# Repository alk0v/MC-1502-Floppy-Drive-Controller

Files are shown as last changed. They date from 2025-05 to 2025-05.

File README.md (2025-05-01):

# Floppy Drive Controller for Electronika MC-1502 computer
Replica of Floppy Drive Controller for Electronica MC-1502 Computer
Based on the original PCB, Zorel and Val_DP remakes.
The original design was developed in Jun 1991 by Kurapin (design), Tokar (checked), Safat (tested), and Teslenko (approved).

MC1502_FDC_Gerber

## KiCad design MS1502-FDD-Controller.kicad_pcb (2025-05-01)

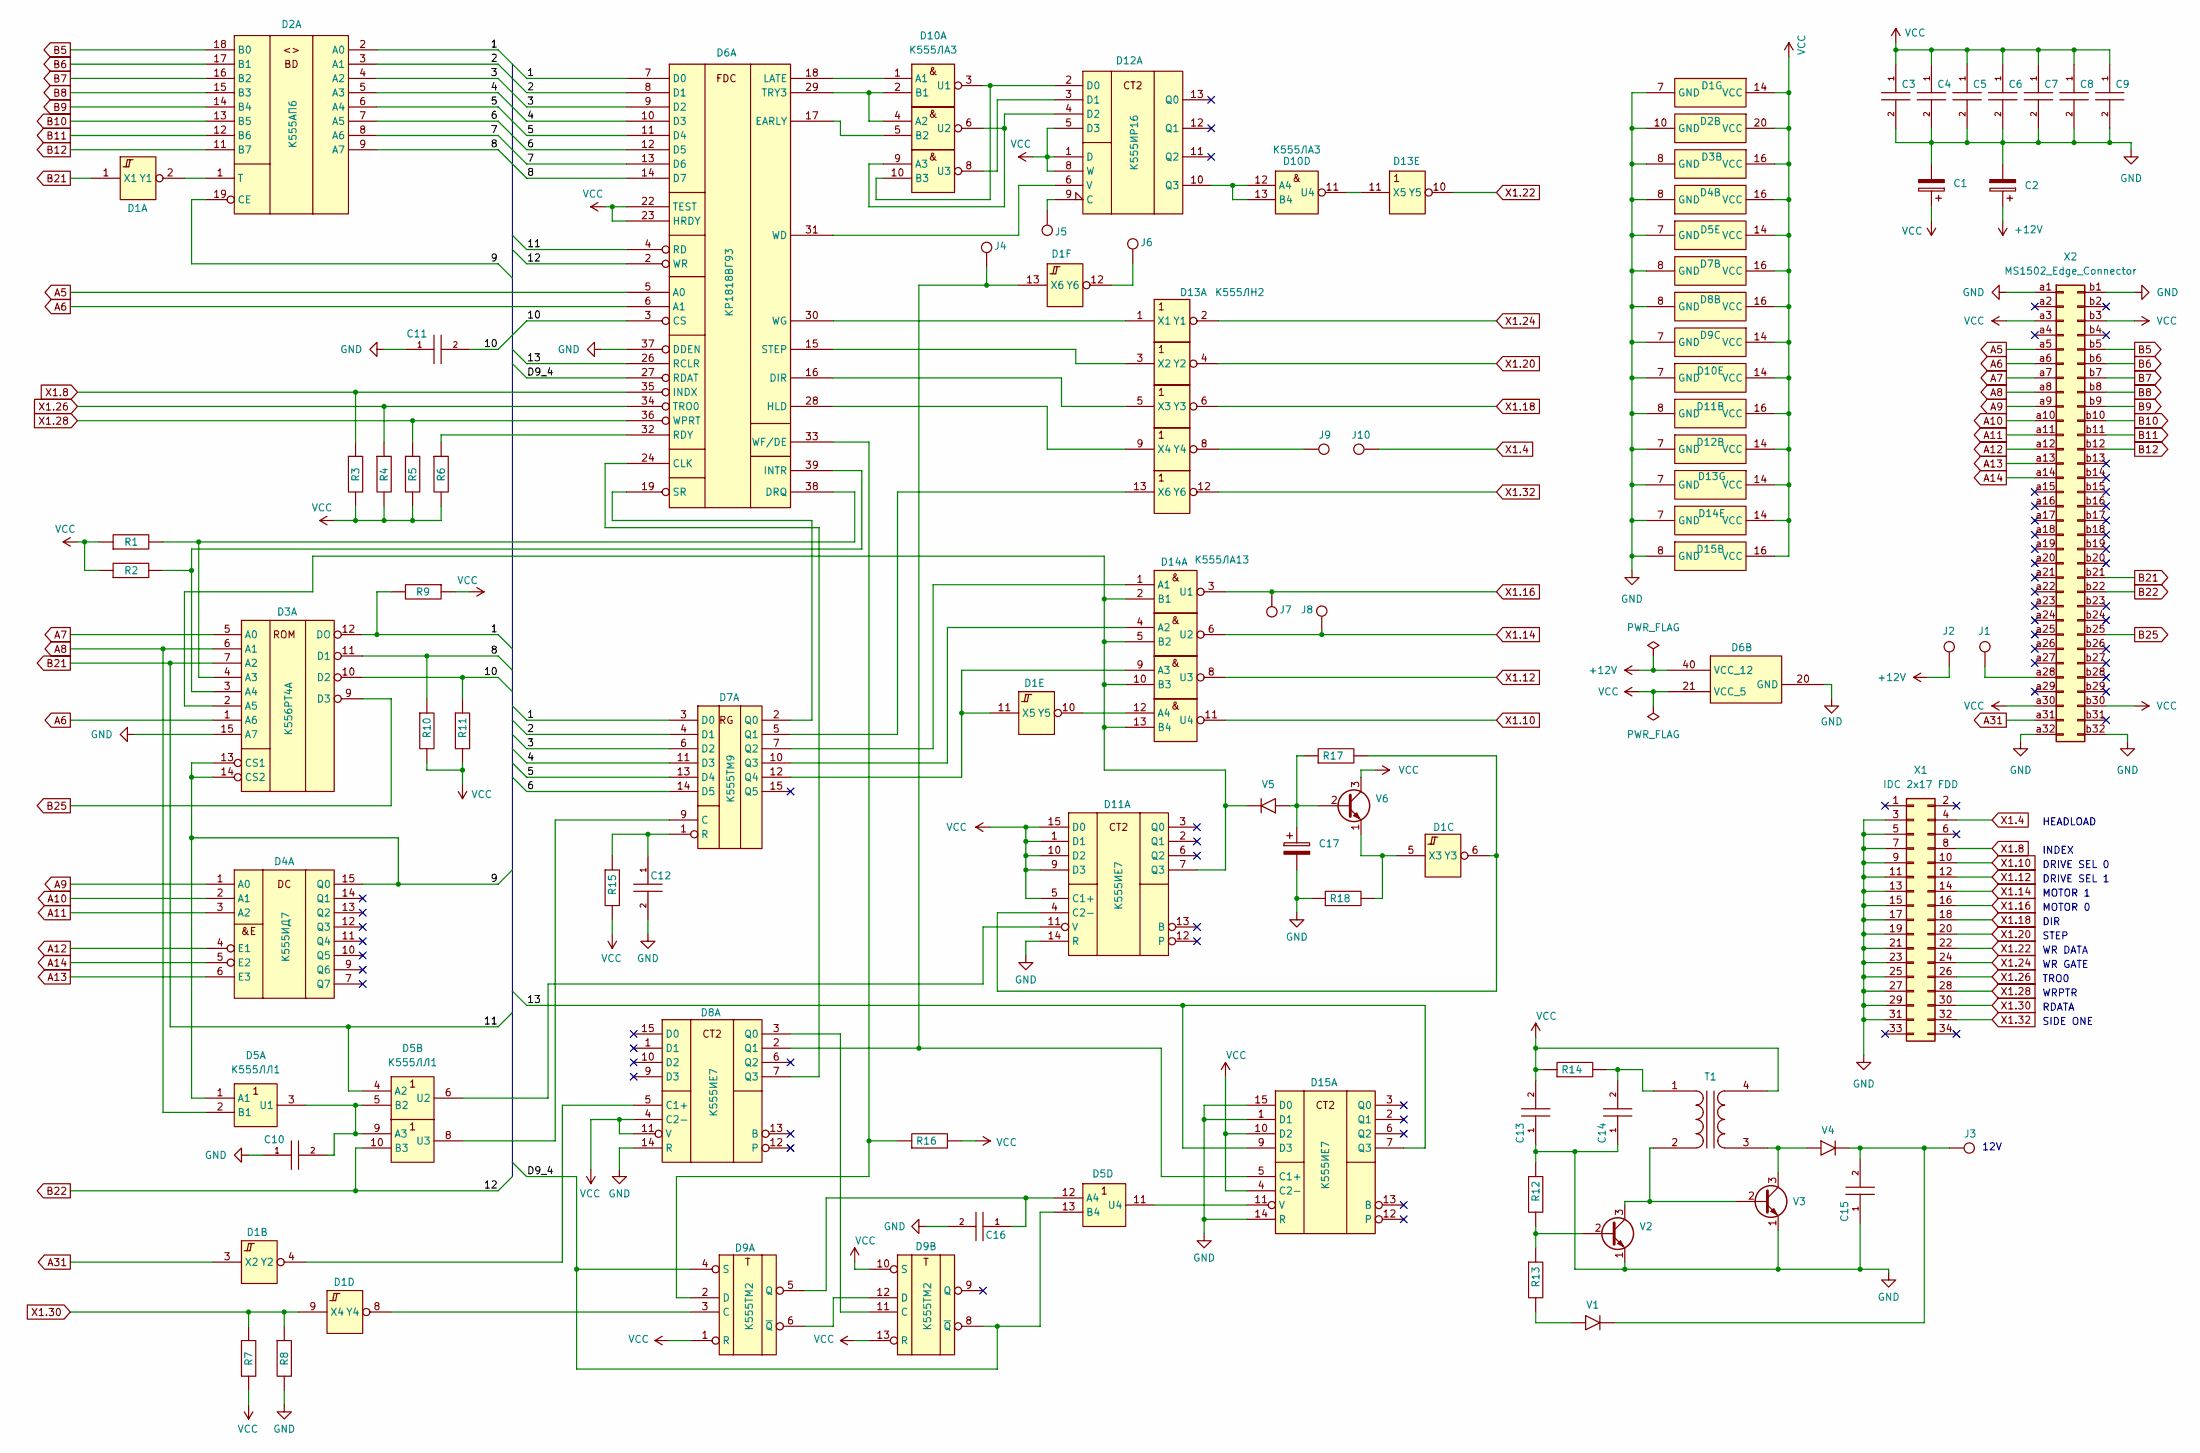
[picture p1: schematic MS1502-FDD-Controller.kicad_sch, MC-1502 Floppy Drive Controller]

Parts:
C1: 47uFx16V; CP_Radial_D5.0mm_P2.50mm
C2, C17: 47uFx16V; CP_Radial_D5.0mm_P2.00mm
C3, C6, C12: 150 nF; cap_4mm
C4, C5, C7, C8, C9, C13, C14, C15: 150 nF; cap_5mm
C10, C11, C16: 100 pF; cap_5mm
D1: К555ТЛ2; 201.14-8
D2: К555АП6; 2140.20-1
D3: К556РТ4А; 201.16.5
D4: К555ИД7; 201.16.5
D5: К555ЛЛ1; 201.14-8
D6: КР1818ВГ93; 2123.40-6
D7: К555ТМ9; 201.16.5
D8, D11, D15: К555ИЕ7; 201.16.5
D9: К555ТМ2; 201.14-8
D10: К555ЛА3; 201.14-8
D12: К555ИР16; 201.14-8
D13: К555ЛН2; 201.14-8
D14: К555ЛА13; 201.14-8
J1, J2, J3, J4, J5, J6, J7, J8, J9, J10: round_pin
R1, R2, R10, R16, R17: 10 kOhm; 2pin_100
R3, R4, R5, R6, R7, R11: 560 Ohm; 2pin_100
R8: 1,2 kOhm; 2pin_100
R9: 10 kOhm; 2pin_0875
R12: 2 kOhm; 2pin_100
R13: 1 kOhm; 2pin_100
R14, R18: 820 Ohm; 2pin_100
R15: 4,7 kOhm; 2pin_100
T1: Transformer_1P_1S; transformer_1
V1: КС211Ж; 2pin_150_polar
V2, V6: КТ315Г; VT_5mm
V3: КТ817Г; VT_TO126
V4, V5: КД522Б; 2pin_150_polar
X1: IDC 2x17 FDD; IDC-Header_2x17_P2.54mm_Vertical
X2: MS1502_Edge_Connector; MS1502_edge

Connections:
+12V: C2.1, D6.40 (VCC_12), J2.1
/1: D2.2 (A0), D3.12 (DO), D6.7 (D0), D7.3 (D0), R9.2
/2: D2.3 (A1), D6.8 (D1), D7.4 (D1)
/3: D2.4 (A2), D6.9 (D2), D7.6 (D2)
/4: D2.5 (A3), D6.10 (D3), D7.11 (D3)
/5: D2.6 (A4), D6.11 (D4), D7.13 (D4)
/6: D2.7 (A5), D6.12 (D5), D7.14 (D5)
/7: D2.8 (A6), D6.13 (D6)
/8: D2.9 (A7), D3.11 (D1), D6.14 (D7), R10.1
/9: D2.19 (CE), D3.13 (CS1), D3.14 (CS2), D4.15 (Q0), D5.1 (A1)
/10: C11.2, D3.10 (D2), D6.3 (CS), R11.1
/13: D6.26 (RCLR), D15.7 (Q3), D15.9 (D3)
/D9_4: D5.13 (B4), D6.27 (RDAT), D9.4 (S), D9.8 (~Q)
A5: D6.5 (A0), X2.a5
A6: D3.1 (A6), D6.6 (A1), X2.a6
A7: D3.5 (A0), X2.a7
A8: D3.6 (A1), D5.2 (B1), X2.a8
A9: D4.1 (A0), X2.a9
A10: D4.2 (A1), X2.a10
A11: D4.3 (A2), X2.a11
A12: D4.4 (E1), X2.a12
A13: D4.6 (E3), X2.a13
A14: D4.5 (E2), X2.a14
A31: D1.3 (X2), X2.a31
B5: D2.18 (B0), X2.b5
B6: D2.17 (B1), X2.b6
B7: D2.16 (B2), X2.b7
B8: D2.15 (B3), X2.b8
B9: D2.14 (B4), X2.b9
B10: D2.13 (B5), X2.b10
B11: D2.12 (B6), X2.b11
B12: D2.11 (B7), X2.b12
B21: D1.1 (X1), D3.7 (A2), D5.4 (A2), D6.4 (RD), X2.b21
B22: D5.10 (B3), D6.2 (WR), X2.b22
B25: D3.9 (D3), X2.b25
GND: C1.2, C2.2, C3.2, C4.2, C5.2, C6.2, C7.2, C8.2, C9.2, C10.1, C11.1, C12.2, C13.1, C14.1, C15.1, C16.2, C17.2, D1.7 (GND), D2.10 (GND), D3.8 (GND), D3.15 (A7), D4.8 (GND), D5.7 (GND), D6.20 (GND), D6.37 (DDEN), D7.8 (GND), D8.8 (GND), D8.14 (R), D9.7 (GND), D10.7 (GND), D11.8 (GND), D11.14 (R), D12.7 (GND), D13.7 (GND), D14.7 (GND), D15.1 (D1), D15.8 (GND), D15.14 (R), D15.15 (D0), R8.2, R12.1, R18.1, V2.1 (E), V3.1 (E), X1.3, X1.5, X1.7, X1.9, X1.11, X1.13, X1.15, X1.17, X1.19, X1.21, X1.23, X1.25, X1.27, X1.29, X1.31, X2.a1, X2.a32, X2.b1, X2.b32
unnamed: C15.2, J3.1, V1.2, V4.2
unnamed: D1.2 (Y1), D2.1 (T)
unnamed: D1.4 (Y2), D8.5 (C1+)
unnamed: D1.5 (X3), R18.2, V6.1 (E)
unnamed: D1.8 (Y4), D9.3 (C)
unnamed: D1.12 (Y6), J6.1
unnamed: D3.4 (A3), D6.38 (DRQ), R1.2
unnamed: D3.3 (A4), D6.39 (INTR), R2.2
unnamed: C10.2, D5.3 (U1), D5.5 (B2), D5.9 (A3)
unnamed: D5.8 (U3), D7.9 (C)
unnamed: C16.1, D5.12 (A4), D9.5 (Q)
unnamed: D6.24 (CLK), D8.7 (Q3)
unnamed: D6.32 (RDY), R6.1
unnamed: D6.19 (SR), D7.2 (Q0)
unnamed: D6.33 (WF/DE), D9.2 (D), R16.1
unnamed: C12.1, D7.1 (R), R15.1
unnamed: D8.3 (Q0), D9.11 (C)
unnamed: D9.6 (~Q), D9.12 (D)
unnamed: D6.18 (LATE), D10.1 (A1)
unnamed: D6.29 (TRY3), D10.2 (B1), D10.4 (A2)
unnamed: D10.3 (U1), D10.10 (B3), D12.2 (D0)
unnamed: D6.17 (EARLY), D10.5 (B2)
unnamed: D10.6 (U2), D10.9 (A3), D12.4 (D2)
unnamed: D10.8 (U3), D12.3 (D1)
unnamed: D10.12 (A4), D10.13 (B4), D12.10 (Q3)
unnamed: D10.11 (U4), D13.11 (X5)
unnamed: D1.6 (Y3), D11.4 (C2-), R17.2
unnamed: D3.2 (A5), D11.7 (Q3), D14.2 (B1), D14.5 (B2), D14.10 (B3), D14.13 (B4), V5.2
unnamed: D5.6 (U2), D11.11 (V)
unnamed: D12.9 (C), J5.1
unnamed: D6.31 (WD), D12.6 (V)
unnamed: D6.30 (WG), D13.1 (X1)
unnamed: D6.15 (STEP), D13.3 (X2)
unnamed: D6.16 (DIR), D13.5 (X3)
unnamed: D6.28 (HLD), D13.9 (X4)
unnamed: D13.8 (Y4), J9.1
unnamed: D7.5 (Q1), D13.13 (X6)
unnamed: D7.7 (Q2), D14.1 (A1)
unnamed: D7.10 (Q3), D14.4 (A2)
unnamed: D1.11 (X5), D7.12 (Q4), D14.9 (A3)
unnamed: D1.10 (Y5), D14.12 (A4)
unnamed: D1.13 (X6), D8.2 (Q1), D15.5 (C1+), J4.1
unnamed: D5.11 (U4), D15.11 (V)
unnamed: R13.2, V1.1
unnamed: C14.2, R14.2, T1.1 (AA)
unnamed: T1.2 (AB), V2.3 (C), V3.2 (B)
unnamed: T1.3 (SA), V3.3 (C), V4.1
unnamed: R12.2, R13.1, V2.2 (B)
unnamed: C17.1, R17.1, V5.1, V6.2 (B)
unnamed: J1.1, X2.a28
VCC: C1.1, C3.1, C4.1, C5.1, C6.1, C7.1, C8.1, C9.1, C13.2, D1.14 (VCC), D2.20 (VCC), D3.16 (VCC), D4.16 (VCC), D5.14 (VCC), D6.21 (VCC_5), D6.22 (TEST), D6.23 (HRDY), D7.16 (VCC), D8.4 (C2-), D8.11 (V), D8.16 (VCC), D9.1 (R), D9.10 (S), D9.13 (R), D9.14 (VCC), D10.14 (VCC), D11.1 (D1), D11.5 (C1+), D11.9 (D3), D11.10 (D2), D11.15 (D0), D11.16 (VCC), D12.1 (D), D12.5 (D3), D12.8 (W), D12.14 (VCC), D13.14 (VCC), D14.14 (VCC), D15.4 (C2-), D15.10 (D2), D15.16 (VCC), R1.1, R2.1, R3.2, R4.2, R5.2, R6.2, R7.2, R9.1, R10.2, R11.2, R14.1, R15.2, R16.2, T1.4 (SB), V6.3 (C), X2.a3, X2.a30, X2.b3, X2.b30
X1.4: J10.1, X1.4
X1.8: D6.35 (INDX), R3.1, X1.8
X1.10: D14.11 (U4), X1.10
X1.12: D14.8 (U3), X1.12
X1.14: D14.6 (U2), J8.1, X1.14
X1.16: D14.3 (U1), J7.1, X1.16
X1.18: D13.6 (Y3), X1.18
X1.20: D13.4 (Y2), X1.20
X1.22: D13.10 (Y5), X1.22
X1.24: D13.2 (Y1), X1.24
X1.26: D6.34 (TRO0), R4.1, X1.26
X1.28: D6.36 (WPRT), R5.1, X1.28
X1.30: D1.9 (X4), R7.1, R8.1, X1.30
X1.32: D13.12 (Y6), X1.32

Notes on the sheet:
HEADLOAD
RDATA
WRPTR
MOTOR 0
WR DATA
DRIVE SEL 0
WR GATE
12V
INDEX
SIDE ONE
DRIVE SEL 1
TRO0
DIR
MOTOR 1
STEP

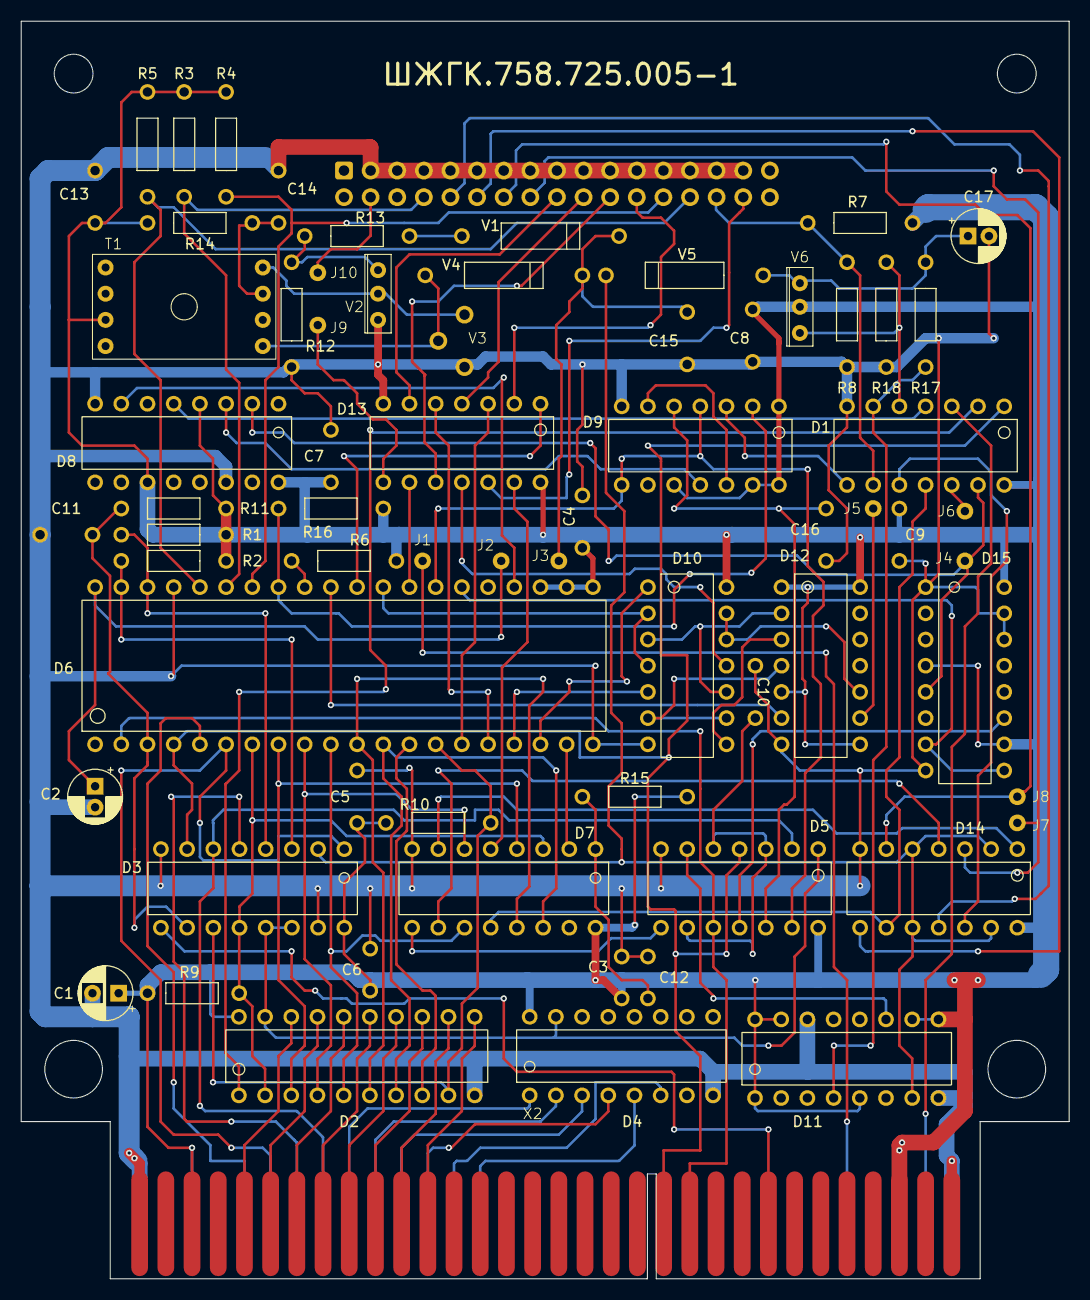
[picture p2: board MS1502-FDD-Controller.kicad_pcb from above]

Board: 2 copper layers, 100.0 x 120.0 mm, 69 parts (1 on the bottom side), 101 nets.
